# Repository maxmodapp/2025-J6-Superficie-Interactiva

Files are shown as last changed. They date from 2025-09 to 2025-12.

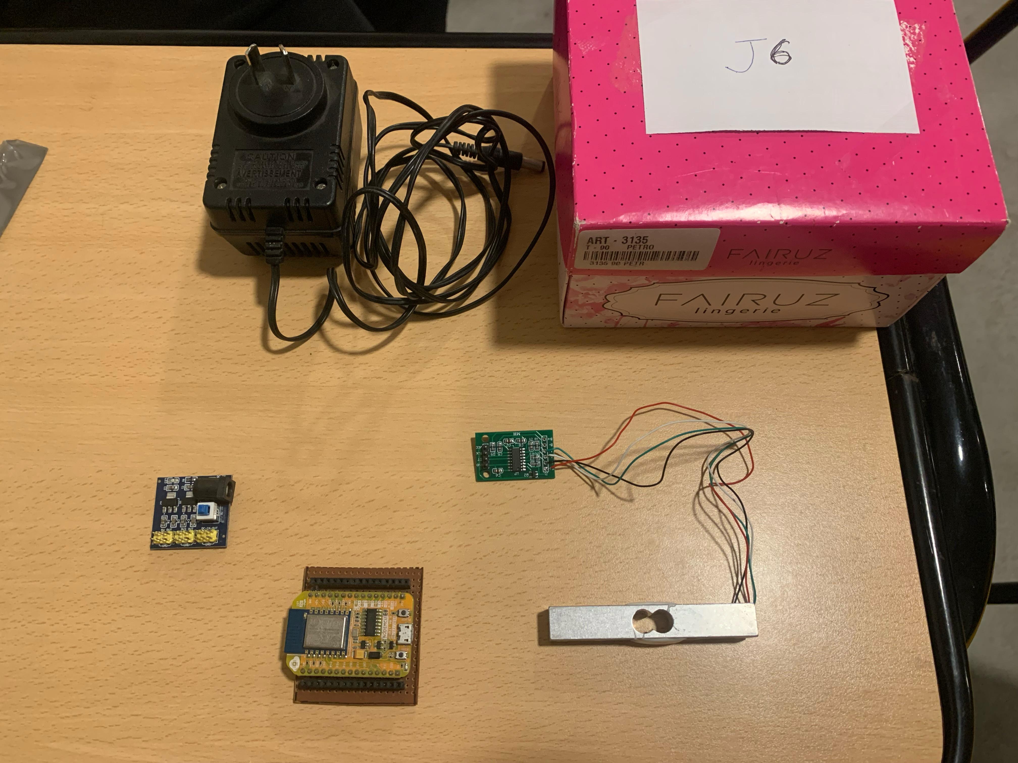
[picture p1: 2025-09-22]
Bitacora/Dispositivos J6.jpg

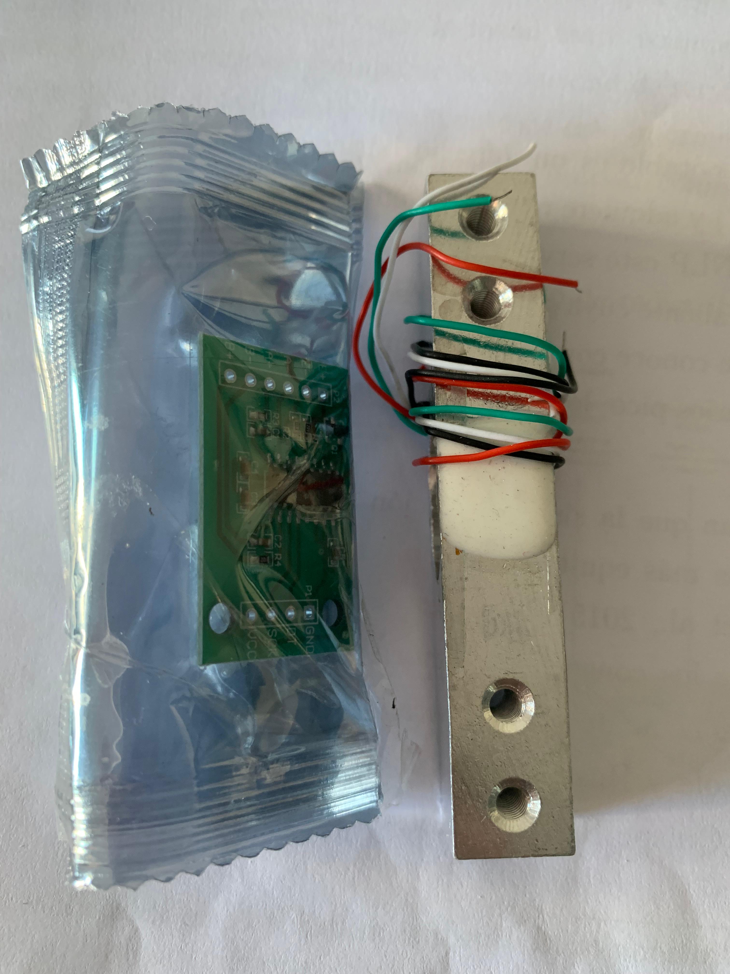
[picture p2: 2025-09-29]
Bitacora/Dispositivos J6 reentregados.jpg

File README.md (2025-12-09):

# 🤖 J6: Multi-Touch Interactive Surface




> **An interactive tactile platform based on force distribution analysis, controlled by the ESP8266 SoC.**

---

## 👨‍💻 Development Team

**Group J6 - 2025**

| Name | Student ID | GitHub Profile |
| :--- | :--- | :--- |
| **Dappiano, Máximo** | 03210/8 | [@maxmodapp](https://github.com/maxmodapp) |
| **Restucha, Tiago** | 03398/7 | [@TiagoRestucha](https://github.com/TiagoRestucha) |
| **Schwindt, Ignacio Andres** | 03229/0 | [@igna-s](https://github.com/igna-s) |

---

## 1. 📝 Introduction

This project involves the development of a tactile platform based on load cells, designed to simultaneously detect the pulses and movements of objects.

Inspired by the **MIT Media Lab SCALE system**, which utilizes distributed sensor networks to capture the magnitude and shape of applied force, our approach focuses on a reduced sensor array (triangulation) to achieve two-dimensional detection. The ultimate goal is to create a device analogous to a large-scale **touchpad** or mousepad capable of recognizing multiple interaction types, such as:
* **Tracking:** Real-time position estimation.
* **Drag:** Moving objects across the surface.
* **Push:** Detecting pressure intensity gestures (Z-axis).

---

## 2. 🎯 Objectives and Scope

The platform is designed to detect the force and position of contacts on a rigid surface. It enables interaction through gestures, opening new possibilities for tangible user interfaces.

### Primary Objectives (Fundamentals)
* **🏗️ Structure:** Develop a robust physical structure housing three load cells distributed in an equilateral triangle configuration. ✅
* **🔌 Electronics:** Implement the necessary circuitry to read analog outputs from the load cells using **HX711** (24-bit ADC) modules.✅
* **🧠 Algorithms:** Design firmware algorithms that, based on combined sensor readings, calculate the **2D position (X, Y)** of a load and detect **displacement**.✅
* **🖥️ Interface:** Develop a reactive **Web Interface** that visualizes the object's position and force intensity in real-time.✅
* **🧪 Validation:** Validate the prototype's performance through systematic testing and document the design to ensure reproducibility.✅

### Secondary Objectives
* **📈 Management:** Execute structured project management and analyze the feasibility of future feature expansions.✅
* **📦 Design:** Refine the industrial design to favor potential commercial adoption or academic demonstration.✅

---

## 3. 🏗️ Technical Architecture

The system operates on a **Barycentric Coordinate** principle.

The platform consists of **three load cells ($S_{1}, S_{2}, S_{3}$)** placed at strategic points (vertices) of a base. Each cell is connected to an **HX711 amplifier**, which digitizes the weight signal.

The core processing unit is an **ESP8266** microcontroller. It performs the following tasks:
1.  **Acquisition:** Reads raw data from the 3 ADCs.
2.  **Filtering:** Applies moving average filters to reduce mechanical noise.
3.  **Calculation:** Computes the Center of Pressure (CoP).
4.  **Transmission:** Sends telemetry (X, Y, Force) via **WebSockets** over Wi-Fi to a connected client.

Finally, a web server (hosted on the ESP8266) presents a visual HTML5 Canvas interface showing the trajectory and gestures.

---

## 4. 🛠️ Hardware Specifications

To replicate this system, the following hardware configuration is used:

| Component | Description | Function |
| :--- | :--- | :--- |
| **ESP8266** | 32-bit MCU, 80MHz, Wi-Fi | Central processing and Web Server. |
| **Load Cells** | 3x Beam Type (5kg) | Force transduction. |
| **HX711** | 3x 24-bit ADCs | Signal amplification and digitization. |
| **Power Supply** | 5V 2A (MicroUSB) | System power. |
---
### Pinout Configuration
The following mapping is used to interface with the three HX711 modules, utilizing specific GPIOs for Data (DT) and Clock (SCK) for each sensor:

* **Module 1:**
  * **DT (Data):** Connected to **GPIO 12 (D6)**.
  * **SCK (Clock):** Connected to **GPIO 14 (D5)**.

* **Module 2:**
  * **DT (Data):** Connected to **GPIO 4 (D2)**.
  * **SCK (Clock):** Connected to **GPIO 5 (D1)**.

* **Module 3:**
  * **DT (Data):** Connected to **GPIO 13 (D7)**.
  * **SCK (Clock):** Connected to **GPIO 15 (D8)**.

---

## 5. 🔬 Theory of Operation

The position of the object is determined by calculating the **Center of Pressure (CoP)**. Assuming the sensors are arranged in a triangle, the coordinates $(X, Y)$ are derived from the weighted average of the forces $F_i$ measured at each vertex $(x_i, y_i)$.

### Mathematical Model

$$
F_{total} = \sum_{i=1}^{3} F_i
$$

$$
X_{cop} = \frac{\sum (F_i \cdot x_i)}{F_{total}} \quad , \quad Y_{cop} = \frac{\sum (F_i \cdot y_i)}{F_{total}}
$$

Where:
* $F_i$: Force measured by sensor $i$ (after tare).
* $x_i, y_i$: Physical coordinates of sensor $i$ relative to the center of the plate.

---

## 6. 🚀 Installation & Usage

1.  **Hardware Assembly:** Print the parts located in `/Estructura Fisica` and assemble the sensors in a triangular layout.
2.  **Firmware Upload:**
    * Open the project in `/Codigos` using **Arduino IDE** or **PlatformIO**.
    * Install the `HX711` and `WebSockets` libraries.
    * Upload the code to the ESP8266.
3.  **Calibration:**
    * Run the calibration sketch first to determine the scaling factor for your specific load cells.
    * Update the `calibration_factor` variable in the main firmware.
4.  **Run:**
    * Connect to the Wi-Fi network generated by the ESP8266 (or the network specified in code).
    * Open your browser and navigate to the IP address printed in the Serial Monitor.
    * Interact with the surface and observe the visual feedback.

---

## 📚 References

1.  **MIT Media Lab.** (n.d.). *SCALE: Distributed Sensing*. [Link](https://tangible.media.mit.edu/project/scale/)
2.  **Dwyer Omega.** *What is a Load Cell?* [Link](https://www.dwyeromega.com/en-us/resources/load-cells)
3.  **SparkFun Electronics.** *HX711 Datasheet & Hookup Guide*. [Link](https://learn.sparkfun.com/tutorials/load-cell-amplifier-hx711-breakout-hookup-guide)

---
*© 2025 Group J6. Released under the GPL-3.0 License.*

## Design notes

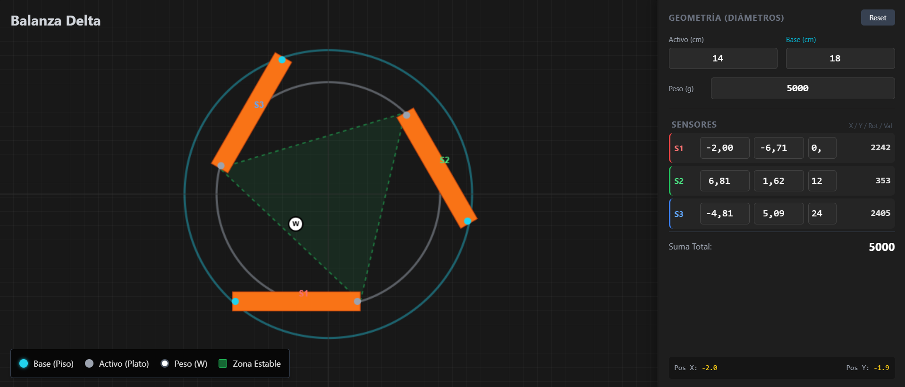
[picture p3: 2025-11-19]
Simulacion/simulacion_html.png

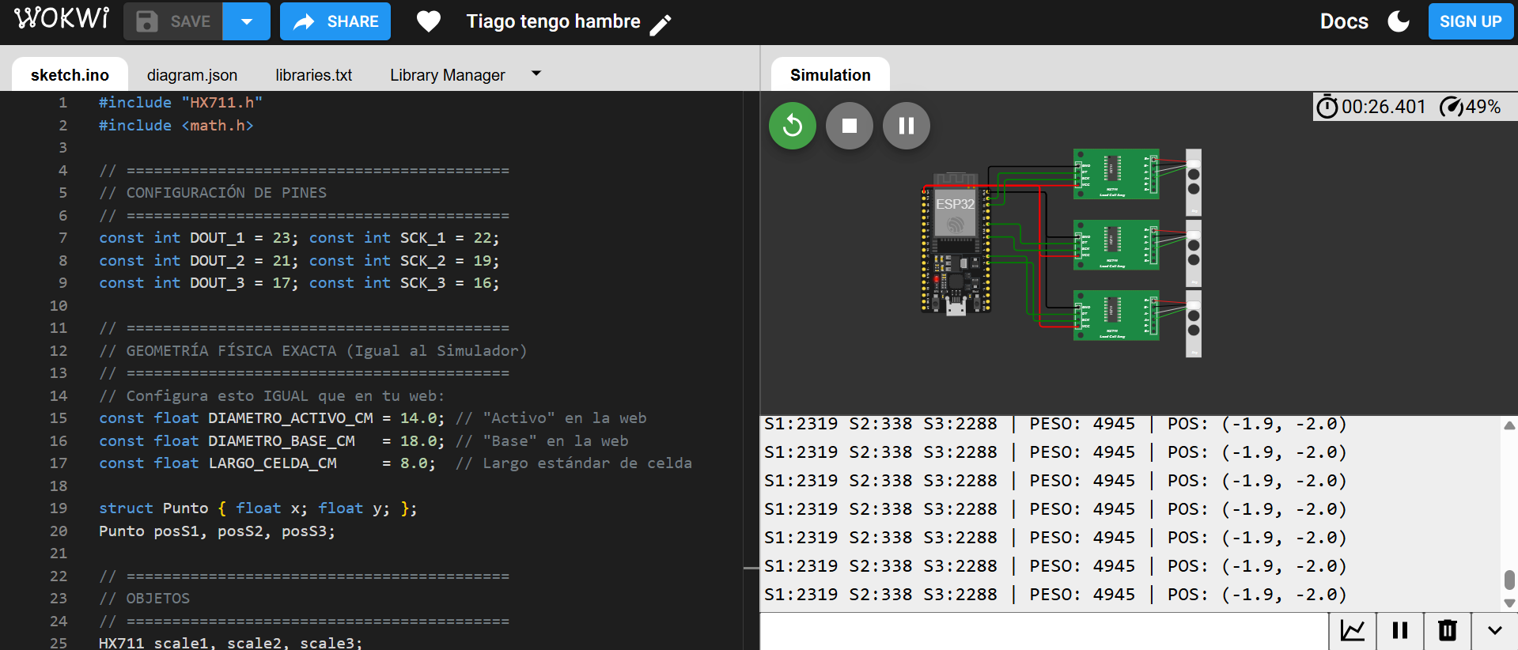
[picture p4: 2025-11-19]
Simulacion/simulacion_galgas.png

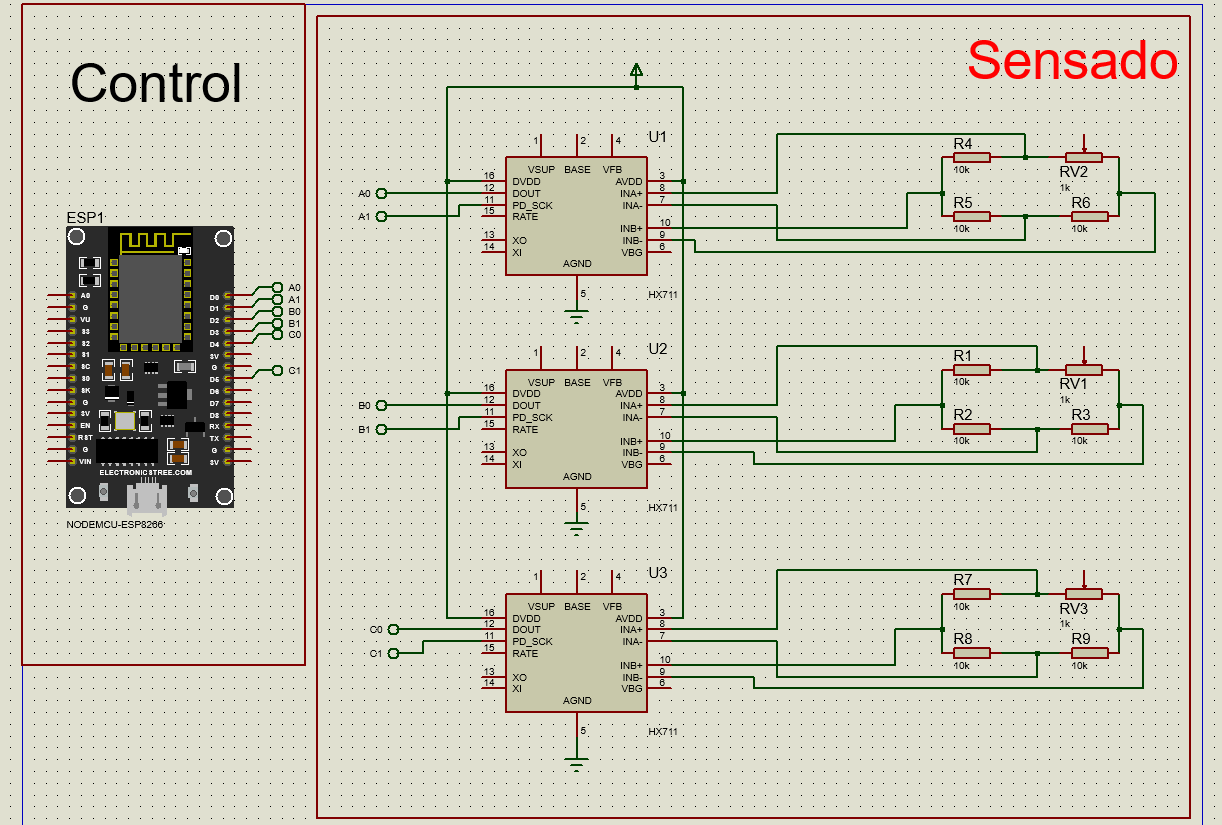
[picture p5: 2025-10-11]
Esquematico/Esquemático.png

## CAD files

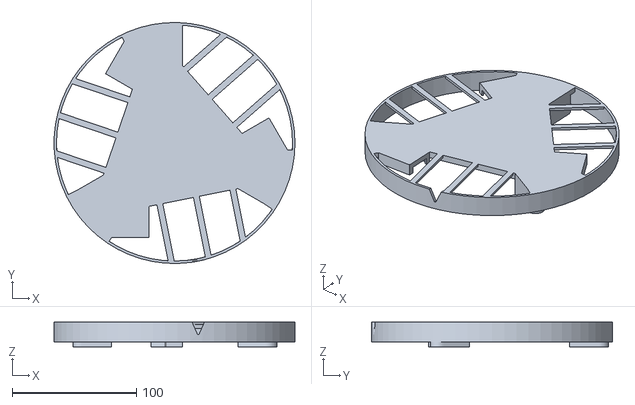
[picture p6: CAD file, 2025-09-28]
Estructura Fisica/base.STL
194.0 x 193.9 x 20.0

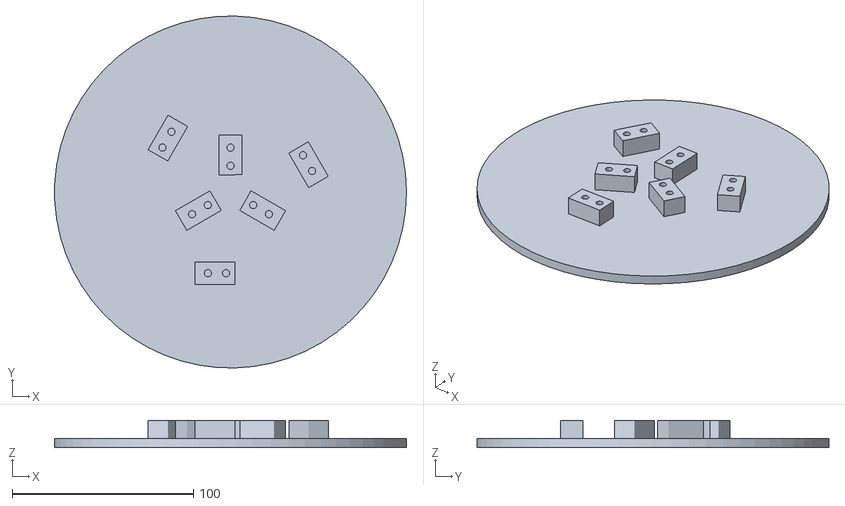
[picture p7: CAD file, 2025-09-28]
Estructura Fisica/tapa.STL
194.0 x 193.9 x 15.0

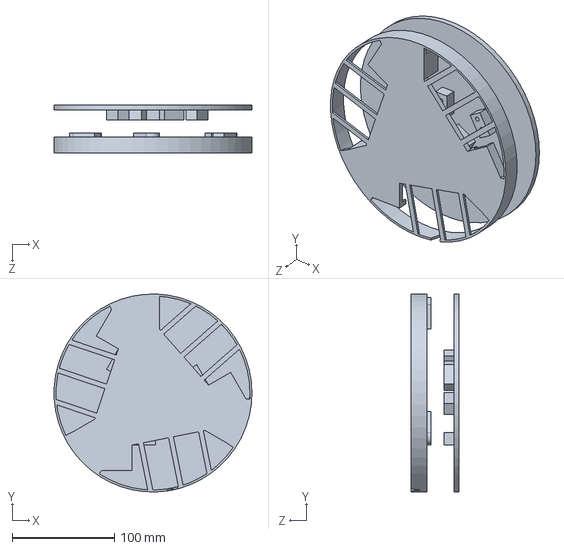
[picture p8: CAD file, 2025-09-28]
Estructura Fisica/Pieza1.SLDPRT
194.0 x 193.9 x 47.5 mm

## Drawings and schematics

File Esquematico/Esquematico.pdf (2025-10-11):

# Control

RV2

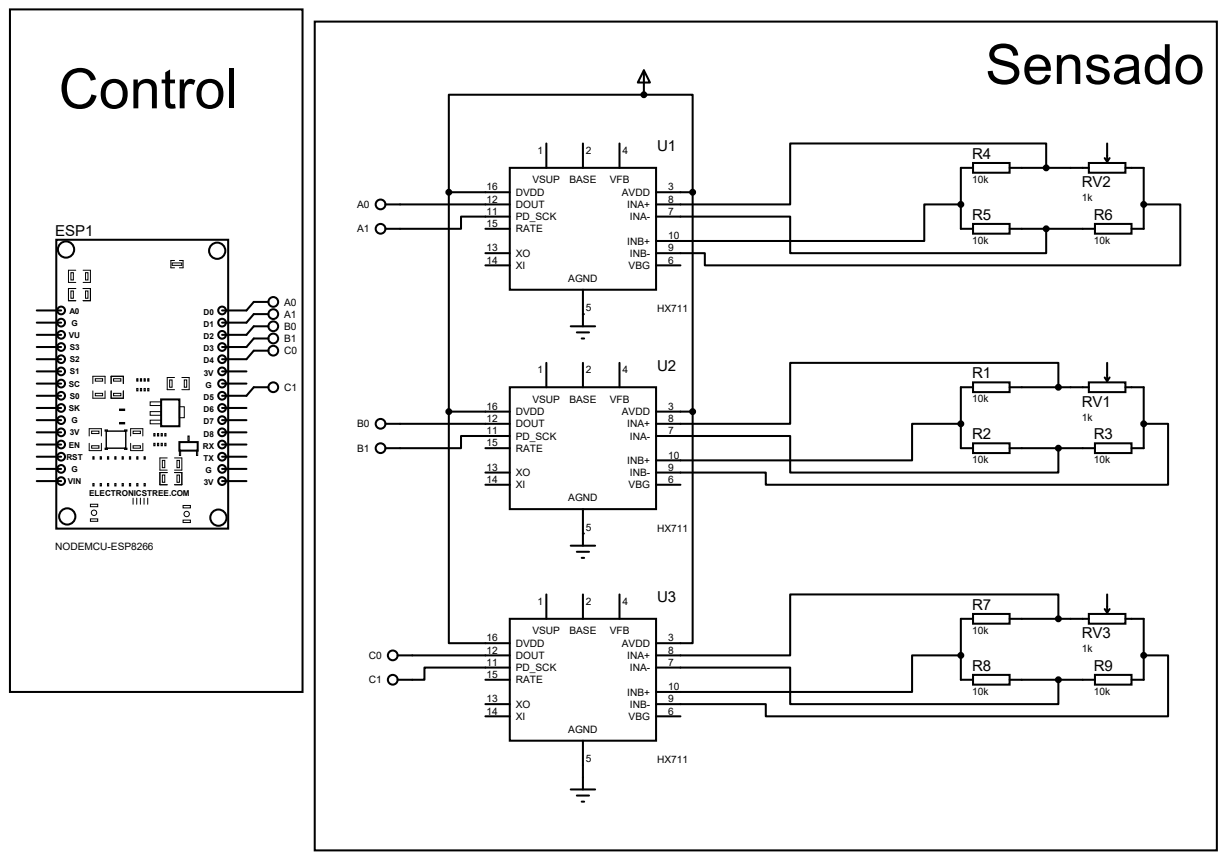
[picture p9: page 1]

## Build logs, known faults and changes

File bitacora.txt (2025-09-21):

# Descripción breve de la actividad
Se implementó la primera versión de la bitácora para el proyecto.

| Fecha | Hora | Autor | Actividad | Estado | Notas / Comentarios |
|---|---|---|---|---|---|
| 2025-09-21 | 14:00  | Ignacio S.  | Creación de la bitácora inicial  | Completado  | Archivo de texto generado correctamente. |

# Descripción breve de la actividad
Se esta creando un esquema en Proteus V8, con las conecciones correspondientes.

| Fecha | Hora | Autor | Actividad | Estado | Notas / Comentarios |
|---|---|---|---|---|---|
| 2025-09-21 | 14:17  | Ignacio S.  | Creación esquema conexiones | En Proceso  | N/a |
| 2025-09-21 | 15:37  | Ignacio S.  | Creación esquema conexiones | En Proceso  | Problematica....No existe celda de carga en Proteus ni procesador, revisar conexiones|

# Descripción breve de la actividad
Se creo un prottotipo de readme, cuando se avance con el proyecto se editara para que sea consistente (Ej el modulo de carga que no es SP32 y se cambo por otro)

| Fecha | Hora | Autor | Actividad | Estado | Notas / Comentarios |
|---|---|---|---|---|---|
| 2025-09-21 | 16:33  | Ignacio S.  | Creación Readme a partir Plan Pr.| En Proceso  | N/a |

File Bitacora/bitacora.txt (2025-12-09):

# Descripción breve de la actividad
Armado de documentacion.

| Fecha | Hora | Autor | Actividad | Estado | Notas / Comentarios |
|---|---|---|---|---|---|
| 2025-09-21 | 14:00  | Todos | Primera entrega | Finalizado  | N/A |
| 2025-10-11 | 16:00  | Todos | Informe de Avance Octubre | Finalizado  | N/A |
| 2025-11-19 | 16:00  | Todos | Informe de Avance Noviembre | En Proceso  | N/A |

# Descripción breve de la actividad
Se creo un prototipo de readme en Ingles, cuando se avance con el proyecto se editara para que sea consistente (Ej el modulo de carga que no es ESP32 y se cambo por otro)

| Fecha | Hora | Autor | Actividad | Estado | Notas / Comentarios |
|---|---|---|---|---|---|
| 2025-09-21 | 16:33  | Ignacio S.  | Creación Readme a partir Plan Pr.| En Proceso  | N/a |
| 2025-11-19 |17:30 |Ignacio S. |Actualizacion bitacora | finaliado |N/a |

# Descripción breve de la actividad
Se esta creando un esquema en Proteus V8, con las conecciones correspondientes.

| Fecha | Hora | Autor | Actividad | Estado | Notas / Comentarios |
|---|---|---|---|---|---|
| 2025-09-21 | 14:17  | Ignacio S.  | Creación esquema conexiones | En Proceso  | N/a |
| 2025-09-21 | 15:37  | Ignacio S.  | Creación esquema conexiones | En Proceso  | Problematica....No existe celda de carga en Proteus ni procesador, revisar conexiones|
| 2025-09-22 | 18:33  | Todos (DS)  | Creación esquema conexiones | Finalizado  | |

# Descripción breve de la actividad
Diseño estructural

| Fecha | Hora | Autor | Actividad | Estado | Notas / Comentarios |
|---|---|---|---|---|---|
| 2025-09-28 | 10:55  | Ignacio S.  | Diseno Solidworks. Incio | En Proceso  | N/a !
| 2025-09-28 | 16:55  | Ignacio S.  | Diseno Solidworks. Fin, mando STL| Finalizado  | En espera de la impresion 3D para poder contnuar !
| 2025-10-01 | 12:00  | Ignacio S.  |Impresion 3D bajo cargo personal  | Finalizado  | !
| 2025-10-07 | 13:00  | Tiago R. .  |Ensamblaje del prototipo | Finalizado  | !

# Descripción breve de la actividad
Evidencia
| Fecha      | Hora   | Autor       | Actividad            | Estado      |Notas / Comentarios                                                                         |
|------------|--------|-------------|----------------------|-------------!--------------------------------------------------------------------------------------------|
| 2025-09-21 | 21:57  | Tiago R.    |Imagen de Componentes | Completado  |Se agrega evidencia de la entrega de los componentes para el proyecto "Dispoitivos J6"      |
| 2025-09-28 | 17:20  | Tiago R.    |Imagen de Componentes | Completado  |Se agrega evidencia de la entrega del resto de los componetes en particular, 3 galgas de 1kg|
| 2025-09-28 | 17:20  | Todos       |Soldar conexiones     | Completado  | Acudir al ATEI para soldar las 3 galgas de 1kg a sus respectivos hx711                     |
| 2025-09-28 | 19:00  | Todos       |Devolucion galga 20kg | Completado  | Se devolivo la Galga de 20kg                                                               |
| 2025-11-06 | 19:00  | Todos       |Actualizacion de dev. | Completado  | Se devolivo la fuente defectuosa y los 3 hx, se consiguio una fuente de 5v                 |

# Descripción breve de la actividad
Primer codigo de prueba
| Fecha      | Hora   | Autor       | Actividad            | Estado      |Notas / Comentarios                                                                         |
|------------|--------|-------------|----------------------|-------------!--------------------------------------------------------------------------------------------|
| 2025-09-28 | 17:20  | Todos       | Codigo de test       | En Proceso  |n/a                                                                                         |
| 2025-09-28 | 17:38  | Todos       | Codigo de test       | Completado  |Se agrego el codigo de prueba y se verifico el correcto funcionamiento de todos los componen|
|            |        |             |                      |             |tes menos las 3 galgas de 1kg ya que deben ser soldadas a los HX711                         |

# Descripción breve de la actividad
Primer codigo de prueba
| Fecha      | Hora   | Autor       | Actividad                   | Estado      |Notas / Comentarios    
|------------|--------|-------------|-----------------------------|-------------!--------------------------------------------------------------------------------------------|
| 2025-10-22 |16:30   |Maximo. D    |coddigo test conexion esp8266| finaliado   |falta modularizar                                                                           |

# Descripción breve de la actividad
PROBLEMATICA BALANZA
| Fecha      | Hora   | Autor       | Actividad                    | Estado      |Notas / Comentarios    
|------------|--------|-------------|------------------------------|-------------!--------------------------------------------------------------------------------------------|
| 2025-10-29 |12:30   |Todos        |Analisis de problematica      | En proceso   |No se encontro el problema, el codigo no anda                                              |
| 2025-11-01 |10:30   |Tiago R.     |Analisis de problematica      | En proceso   |No se encontro el problema, el codigo no anda                                              |
| 2025-11-03 |12:30   |Todos        |Analisis de problematica      |  finaliado   |Problema, fuente defectuosa                                                                |

# Descripción breve de la actividad
Simulacion de la balanza
| Fecha      | Hora   | Autor       | Actividad                    | Estado      |Notas / Comentarios    
|------------|--------|-------------|------------------------------|-------------!--------------------------------------------------------------------------------------------|
| 2025-11-19 |17:30   |Ignacio S.   |Sim. func. en Esp32 verificada| finaliado   |Falta testearlo con las galgas, pero ahora sabemos con certeza que el codigo funciona       |

# Descripción breve de la actividad
Resoldado de componentes
| Fecha      | Hora   | Autor       | Actividad                   | Estado      |Notas / Comentarios    
|------------|--------|-------------|-----------------------------|-------------!--------------------------------------------------------------------------------------------|
| ----------  |16:30   |Tiago R.    |Resoldado y veriicaion Hx    |             |                                                                                            |

# Descripción breve de la actividad
Resoldado de componentes
| Fecha      | Hora   | Autor       | Actividad                   | Estado      |Notas / Comentarios    
|------------|--------|-------------|-----------------------------|-------------!--------------------------------------------------------------------------------------------|
| 5/12/25    |        |maximo      |sodado galgas nuevas y verificacion         |   

# Descripción breve de la actividad
armado general
| Fecha      | Hora   | Autor       | Actividad                   | Estado      |Notas / Comentarios    
|------------|--------|-------------|-----------------------------|-------------!--------------------------------------------------------------------------------------------|
| 6/12/25    |        |todos        |armado final                   |           |
| 7/12/25    |        |maximo       |codigo final separado en archivos|         |
| 7/12/25    |        |todos        |correcion de errores           |           |

fin

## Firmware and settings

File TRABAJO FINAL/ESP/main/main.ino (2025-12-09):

// main.ino
#include <ESP8266WiFi.h>
#include <ESPAsyncTCP.h>
#include <ESPAsyncWebServer.h>
#include <ArduinoJson.h>
#include <dummy.h>
#include <HX711.h>

void setup() {
  Serial.begin(115200);
  delay(100);

  initWiFi();        // conexion.ino
  initWebSocket();   // conexion.ino
  initScales();      // scales.ino

  Serial.println("Setup completo");
}

void loop() {
  //leer galgas y actualizar g_f1,g_f2,g_f3,g_W,g_x,g_y
  updateScales();

  //enviar posición/peso por WebSocket
  sendPositionWS();

  //por las dudas
  yield();
}

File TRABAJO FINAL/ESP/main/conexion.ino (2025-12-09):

//#include <ESP8266WiFi.h>
//#include <ESPAsyncTCP.h>
//#include <ESPAsyncWebServer.h>
//#include <ArduinoJson.h>

// #include <ESP8266mDNS.h>

//CONFIG
const char* WIFI_SSID = "Pupi";
const char* WIFI_PASS = "44487105az";
const uint16_t HTTP_PORT = 80;
const char* WS_PATH = "/ws";

unsigned long PUSH_MS = 100;   // 100 ms = 10 Hz

//GLOBAL
AsyncWebServer server(HTTP_PORT);
AsyncWebSocket ws(WS_PATH);

//definidas en scales.ino
extern float g_x;
extern float g_y;
extern float g_W;

unsigned long lastPush = 0;

void onWsEvent(AsyncWebSocket *server,
               AsyncWebSocketClient *client,
               AwsEventType type,
               void *arg,
               uint8_t *data,
               size_t len) {
  if (type == WS_EVT_CONNECT) {
    Serial.printf("[WS] Cliente %u conectado (%s)\n",
                  client->id(), client->remoteIP().toString().c_str());
    client->text("{\"type\":\"hello\",\"msg\":\"ESP8266 listo (testing)\"}");
  } else if (type == WS_EVT_DISCONNECT) {
    Serial.printf("[WS] Cliente %u desconectado\n", client->id());
  } else if (type == WS_EVT_DATA) {
    AwsFrameInfo *info = (AwsFrameInfo*)arg;
    if (info->final && info->index == 0 && info->len == len && info->opcode == WS_TEXT) {
      
      String msg;
      msg.reserve(len + 1);                    
      msg.concat((const char*)data, len);        

      Serial.printf("[WS] RX: %s\n", msg.c_str());
      if (msg == "ping") client->text("{\"type\":\"pong\"}");

    }
  }
}
void initWiFi() {
  WiFi.mode(WIFI_STA);
  WiFi.begin(WIFI_SSID, WIFI_PASS);
  Serial.printf("Conectando a %s", WIFI_SSID);

  int attempts = 0;
  while (WiFi.status() != WL_CONNECTED && attempts < 80) {
    delay(250);
    Serial.print(".");
    attempts++;
    yield(); 
  }
  Serial.println();

  if (WiFi.status() == WL_CONNECTED) {
    Serial.print("WiFi OK. IP: ");
    Serial.println(WiFi.localIP());
  } else {
    Serial.println("No se pudo conectar al WiFi (revisá SSID/clave).");
  }
}
void initWebSocket() {
  ws.onEvent(onWsEvent);
  server.addHandler(&ws);

  //prueba
  server.on("/", HTTP_GET, [](AsyncWebServerRequest *req){
    req->send(200, "text/plain", "WS en /ws (testing X,Y,peso)");
  });

  server.begin();
  Serial.println("Servidor WS iniciado");
}


void sendPositionWS() {
  unsigned long now = millis();
  if (now - lastPush < PUSH_MS) return;  
  lastPush = now;

  //usamos las variables calculadas en scales.ino:
  //g_x, g_y, g_W (definidas ahí como globales)
  StaticJsonDocument<128> doc;
  doc["type"] = "pos";
  doc["x"] = g_x;
  doc["y"] = g_y;
  doc["w"] = g_W;

  char out[128];
  size_t n = serializeJson(doc, out, sizeof(out));
  ws.textAll(out, n);
}

/*
void setup() {
  Serial.begin(115200);
  delay(100);

  initWiFi();
  initWebSocket();
  Serial.println("Setup completo");
}


void loop() {
  unsigned long now = millis();
  if (now - lastPush >= PUSH_MS) {
    lastPush = now;

    //simulador de datos
    static float t = 0.0f;
    t += 0.06f;
    float x = 0.7f * XR * sinf(t);
    float y = 0.9f * YR * sinf(t * 0.6f + 1.2f);
    float w = W_BASE + W_AMP * (0.5f * sinf(t * 0.8f) + 0.5f * cosf(t * 0.3f));

    // JSON: {"type":"pos","x":..,"y":..,"w":..}
    StaticJsonDocument<128> doc;
    doc["type"] = "pos";
    doc["x"] = x;
    doc["y"] = y;
    doc["w"] = w;

    char out[128];
    size_t n = serializeJson(doc, out, sizeof(out));
    ws.textAll(out, n);

    yield();
  }
}

*/

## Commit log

2025-09-28 creation of a 3D base structure for the proyect
    [Pieza1.SLDPRT, base.STL, tapa.STL]
2025-10-22 codigo para la conexion de el esp
    falta modularizar
2025-11-19 Simulaciones mientras se sueldan de nuevo los Hx
2025-12-09 entrega final
    todos los codigos, tanto los del esp como los de la pagina web
2025-12-09 Create Nuevo documento de texto.txt

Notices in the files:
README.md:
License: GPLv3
